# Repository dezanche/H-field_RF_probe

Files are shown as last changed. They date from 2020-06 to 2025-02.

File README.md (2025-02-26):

# Shielded Loop Probe for RF Magnetic Fields


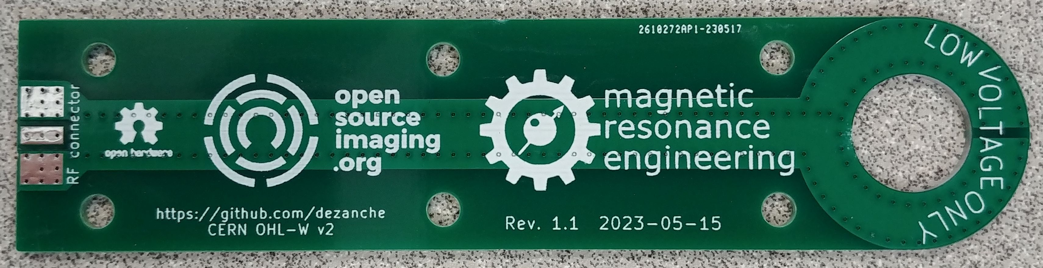
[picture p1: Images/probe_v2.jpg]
photo v2


## Background

Shielded loop probes have a variety of uses in RF engineering, including as "sniffer" probes for electromagnetic (EM) compatibility (EMC) or interference (EMI) measurements in conjunction with a spectrum analyzer. They are also used to measure the H fields of resonant or radiating structures (antennas). In MRI and NMR they are connected to a network analyzer (VNA) to measure the frequency response of RF detector "coils", e.g., to ensure tuning at the Larmor frequency.

VNA Q measurement

The shielded loop was originally described for use as an antenna by **RE Burgess in “The Screened Loop Aerial: A Theoretical and Experimental Investigation”, The Wireless Engineer 16 (October 1939): 492–99**.

## Design

Shielded loop probes are designed to pick up magnetic (H) fields using [Faraday's law of induction](https://en.wikipedia.org/wiki/Faraday%27s_law_of_induction). They are untuned (nonresonant) and have broadband response from a few kHz to several GHz. Output voltage is measured at the probe's terminals which is typically a coaxial connector (e.g., SMA or BNC).

Most of the loop is shielded to minimize sensitivity to electric (E) fields that are often present in addition to the H field. A small gap prevents the shield from shorting the voltage produced by the H field. It is preferable to place the gap in the centre of the loop to maintain symmetry, which ensures that the response will be unchanged if the probe is rotated by 180°.

Shielded loop probes are often made by hand on the RF workbench using semi-rigid, hand-formable or flexible coaxial cable.
Photos, drawings and additional references are found in numerous sites online like https://www.uniteng.com/neildocs/references/Probing_the_Magnetic_Field_Probe.htm

Making loop probes using coax requires some skill and for small diameters it can be challenging. Reliability of the probe can also be an issue because solder joints can fail, and thin coax, even if semi-rigid, can bend quite easily. The probe described here uses a [stripline](https://en.wikipedia.org/wiki/Stripline) printed inside a circuit board (4-layer 1.6 mm FR4 PCB), making it much more rugged and rigid than coax. Connection from the board to coaxial cable is made through a side-launch connector such as the SMA connector shown in the photos below.

The PCB design is provided in both [KiCAD](https://www.kicad.org/) and Gerber format. A similar design is presented in this article: https://www.mdpi.com/2079-9292/10/18/2201

## Insulated Probe Holder
It was suggested by a [user](https://intergalaktik.eu/news/bb3-cm4-emc) that in some situations it might be useful to prevent close contact with the probe. Therefore he designed a [3D printed case](https://github.com/goran-mahovlic/H-field_RF_probe/tree/main/Case) or sleeve for his probe. I have a slightly different SMA connector on mine, and to make it fit we had to modify the case design (see [probe_sleeve.stl](https://github.com/dezanche/H-field_RF_probe/blob/main/probe_sleeve.stl)).
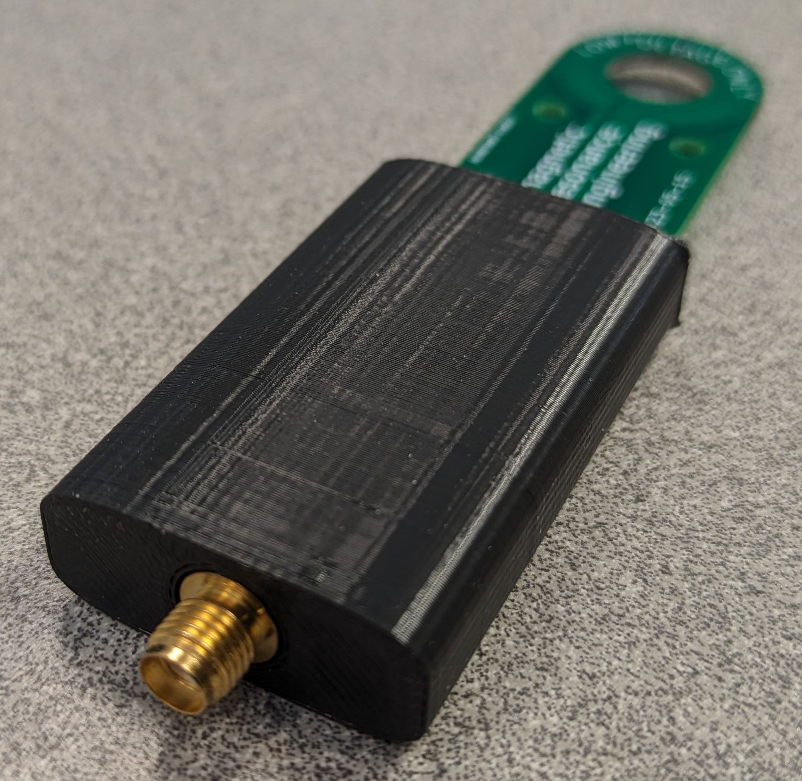
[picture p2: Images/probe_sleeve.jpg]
probe inside sleeve


## Releases

1. The first release (1.0) measures 23mm wide and ~100mm in length. The diameter of the loop is approximately 18mm with a central hole about 11mm ⌀. The panelized version allows 4 identical probes to be printed on a 100mm × 100mm panel (was used because of cost savings from a specific board house). Copies of this board were distributed at the [2019 annual scientific meeting](https://www.ismrm.org/19m/) of the [ISMRM](https://www.ismrm.org/) (Montreal).
This design has a minor flaw: the whole board is covered by ground which can cause perturbation of fields throughout the length of the probe. In many cases the effect will be negligible, but for uses like near field mapping, or accurate measurement of resonance frequency this might be a concern.
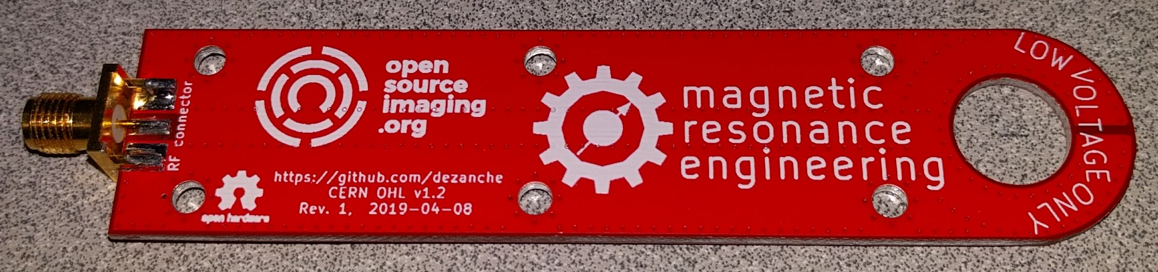
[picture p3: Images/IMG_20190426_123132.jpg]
version 1


2. The second release (2.0) has identical measurements to the previous release and corrects the design flaw by using smaller ground planes. Copies of this board were distributed at the [2023 annual scientific meeting](https://www.ismrm.org/23m/) of the [ISMRM](https://www.ismrm.org/) (Toronto).
signal layer

Lately, probes such as these have become inexpensive and available from various sources online, so it is unlikely that further revisions of this single-loop design will be made.

## Contributors
Nicola De Zanche

Bill Hovestad

## License
Layouts and other CAD files are licensed under the [CERN-OHL-W 2.0 license](https://cern-ohl.web.cern.ch/), version 2.0 or any later version.\
\
All other original content in this repository (including this README file) is licensed under a [Creative Commons Attribution-NoDerivatives 4.0 International License](https://creativecommons.org/licenses/by-nd/4.0/).

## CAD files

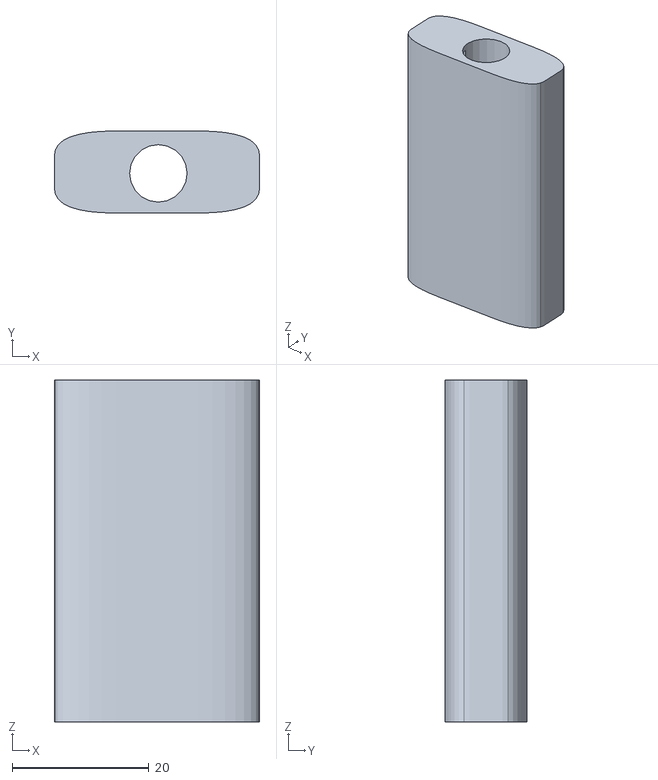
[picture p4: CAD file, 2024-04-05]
probe_sleeve.stl
30.0 x 12.0 x 50.0

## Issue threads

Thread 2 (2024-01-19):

New probe differences

goran-mahovlic, 2024-01-19:
Hi,
first I want to than you for creating this probe!

I have some project with EMI/EMC testing in progress so I will do compare of few open probes and some closed and fancy available in stores.

I have ordered your probes last year, before v2 so I wanted to ask if there is big differences with those two?

I also made simple push in case for the probe I can do pull request if you want to include it in repo or test it.
It is bit bigger so it covers logos, but for me it is good enough...

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

Best,
Goran

dezanche, 2024-01-22:
Hi,
I'm glad you find this probe useful.
The only difference between v1 and v2 is the area covered by the ground planes. You can see the difference in the photos in the readme. There shouldn't be any difference in sensitivity to H fields at the loop but I did not perform a calibration.
Your comparison could be useful if you publish it.
I'd like to try that cool case so go ahead and create the pull request or you can email me the file directly.
Thanks,
nick

goran-mahovlic, 2024-01-23:
> Hi, I'm glad you find this probe useful. The only difference between v1 and v2 is the area covered by the ground planes. You can see the difference in the photos in the readme. There shouldn't be any difference in sensitivity to H fields at the loop but I did not perform a calibration. Your comparison could be useful if you publish it. I'd like to try that cool case so go ahead and create the pull request or you can email me the file directly. Thanks, nick

Tnx!

Here is the latest one.

https://github.com/goran-mahovlic/H-field_RF_probe/blob/main/Case/Probe_holder.stl

I am printing it like this:

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

And then just push probe inside as it it tight fit...

I first had version with screws but then I need screws, so for me this is cheaper and good enough option :)

dezanche, 2024-01-27:
I found it didn't fit the SMA connector I had on mine so we printed a modified version.
Are you using this case for safety or just ergonomics?

goran-mahovlic, 2024-01-28:
Oh, yes my was really tight fit.

For ergonomics and just in case I do not introduce something by touching the active part of the probe

I am working with low voltage only so I am not concerned for safety...

goran-mahovlic, 2024-02-02:
@dezanche I can also do this easier

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

I have used some ooen source camera holder and drilled holes for probe.

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

I need to create some holder for amplifier before working on some code that will move probe...

Will report you about progress...

goran-mahovlic, 2024-02-05:
I have run the 10 minute probe test with your probe, one bought from aliexpress and TekBox one

Someone already compared TekBox with even expensive ones.

https://www.edn.com/review-tekbox-near-field-probes/

My scans are run without any amplifier as older version of ULX3S is good source of emissions.

Green is your probe, Yellow is TekBox one

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

All 3 on one place - red is one I bought from Ali

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

And here is CSV for all 3 if you would like to investigate more.

[trace_data.csv](https://github.com/dezanche/H-field_RF_probe/files/14166752/trace_data.csv)

If you thing we can do something even better let me know.

goran-mahovlic, 2024-02-26:
I will close this issue - my blog post is here

https://intergalaktik.eu/news/bb3-cm4-emc

If you have any suggestions please let me know.

dezanche, 2024-02-27:
Sorry I haven't replied recently. I checked out in your blog: the nice work!
(BTW a couple of the github links are broken)
Thanks for suggesting the case. I will post the modified version that fits the SMA connector I have on my probe
nick

goran-mahovlic, 2024-02-27:
Tnx!

Oh, I did not notice that links are broken but seams underline makes problem with URLs - fixed that now with creating short links for URL.

Cool for the case!

Closed 2024-02-26.

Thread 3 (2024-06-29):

EMC Probe holders v1

goran-mahovlic, 2024-06-29:
Hi again,

as I continued with my experiments I needed to test if some materials will block RF and how much.

In material datasheet I have found that they are using two probes for test, so I have created probe holders.

Design can still be improved, but it serves a purpose.

https://intergalaktik.eu/news/diy-emc-chamber

https://intergalaktik.eu/news/diy-emc-chamber-pyramid

https://github.com/intergalaktik/EMC-experiments/tree/main/EMC-probes-holder

Best way to do the test is with nanoVNA as it will do it fast, for some frequencies like 30MHz it is possible to do it with one tinySA, but for complete range you will need two tinySA devices.

I also do not have good amplifier - will get one soon as in my test material blocks almost complete signal so I am still not able to get material characteristics...

By the way, thank you for adding my work to your README!

dezanche, 2024-07-05:
I'm glad the probe is of use. I wouldn't trust the microwave oven to have a broadband seal at the door, though, because it doesn't have sliding contacts (fingers) all the way around it. I believe microwave ovens get around this by making the gap 1/4 wavelength long (hence the thickness of all microwave oven doors), which looks like a short at the 2.45GHz frequency.

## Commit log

2021-05-28 removing H-field_RF_probe folder
    [H-field_RF_probe.kicad_pcb, H-field_RF_probe.sch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]
2021-11-23 H field probe files
    [H-field_RF_probe.kicad_pcb, H-field_RF_probe.sch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]
2021-11-23 probe files
    [H-field_RF_probe.kicad_pcb, H-field_RF_probe.sch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]
2023-08-15 new Gerbers
    [H-field_RF_probe-B_Cu.gbr, H-field_RF_probe-B_Mask.gbr, H-field_RF_probe-Edge_Cuts.gbr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]
2023-08-15 updated to v2.0 files
    [H-field_RF_probe.kicad_pcb, H-field_RF_probe.kicad_sch, H-field_RF_probe.sch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]
2024-04-05 added sleeve
    [probe_sleeve.stl]
